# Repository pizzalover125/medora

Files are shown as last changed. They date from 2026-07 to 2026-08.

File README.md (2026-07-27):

# medora
A smart pill organizer. A project that saves lives.

### Why medora?
Medication nonadherence is the failure to take medication as prescribed, whether by skipping doses, taking the wrong amount, or stopping treatment early.

* Medication nonadherence contributes to roughly 125,000 deaths every year in the U.S. (Kim and Sarah A.)
* Pill organizer users saw adherence rise from 65% to as high as 100% within months (Rathod et al.)
* Patients using a smart pill organizer were 60% more compliant than those without one, nearly double the 32% improvement seen with a standard pillbox (Godin)

In the status quo, there smart pill organizers are expensive costing an average of $150 - $200 with an added monthly subscription on top. For many Americans, this is simply too out-of-reach. Additionally, many of the apps that come with the organizers are outdated and hard to use. I wanted to fix this by creating a low-cost, modern, smart pill organizer. 

### PCB

The PCB was designed in KiCAD.





### CAD

The CAD was designed in Onshape. You can view the link here: https://cad.onshape.com/documents/c1d6b76cfe1063ae9996d35d/w/b74057f0558c55e37de9882a/e/dce7fc6940c214e434cc5424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. There are magnets that hold together the lid and the case. 





### BOM 
A detailed bill of materials can be viewed here: https://docs.google.com/spreadsheets/d/15uKd0en9vIonSRlWCDsz52HICyDAk6iSbPfcEML8UvA/edit?usp=sharing.

### Credits
Big thanks to Hack Club for making this project possible!

### Sponsorship

This project's PCBs are sponsored by PCBWay, a leading manufacturer for PCB fabrication, assembly, 3D printing, and more.

#### About PCBWay

PCBWay offers PCB prototyping and manufacturing, PCB assembly, 3D printing, CNC machining, and other on-demand manufacturing services for makers, students, and engineers worldwide.

#### Project Background

This is a smart pill organizer — an 8-compartment device with LED indicators to help users track and remember their medication schedule. Building it required a custom PCB to house the microcontroller, LED drivers, and compartment sensors in a compact enclosure.

#### Order Process

1. **Download the Gerber files** from this repo.
2. **Go to [PCBWay.com](https://www.pcbway.com)** and click **"Instant Quote"** on the homepage.
3. **Upload the Gerber `.zip`** from this repo. PCBWay auto-detects your board dimensions, layer count, and other specs — verify these match: 190mm × 90mm, 2-layer.
4. **Set your order specs:**
   - Quantity (e.g. 5 or 10 boards)
   - Board thickness (1.6mm)
   - Copper weight (1oz standard)
   - Surface finish (HASL or ENIG)
   - Solder mask & silkscreen color
5. **Review the quote** and confirm cost/production time.
6. **Place the order** and confirm shipping address/method.
7. **Track production** — PCBWay provides status updates through fabrication and a tracking number once shipped.

#### Unboxing

Will be updated once I receive the boards!

#### Board Dimensions & Precision

Board size: 190 mm × 90 mm
Board thickness: 1.6 mm (standard)
Copper layers: 2-layer
Minimum trace width: 0.2 mm (KiCad default)
Minimum clearance: 0.2 mm (KiCad default)
Via diameter / drill: 0.6 mm / 0.3 mm (KiCad default)
Surface finish: HASL

#### End Application

The board powers the pill organizer's control system — driving LED indicators for each of the 8 compartments and interfacing with the microcontroller to track dosage timing.

#### Why PCBWay
* Fast turnaround for prototyping
* Reliable build quality at low cost for small-batch orders
* Easy Gerber upload and ordering process
* Good support for hobbyist and student projects

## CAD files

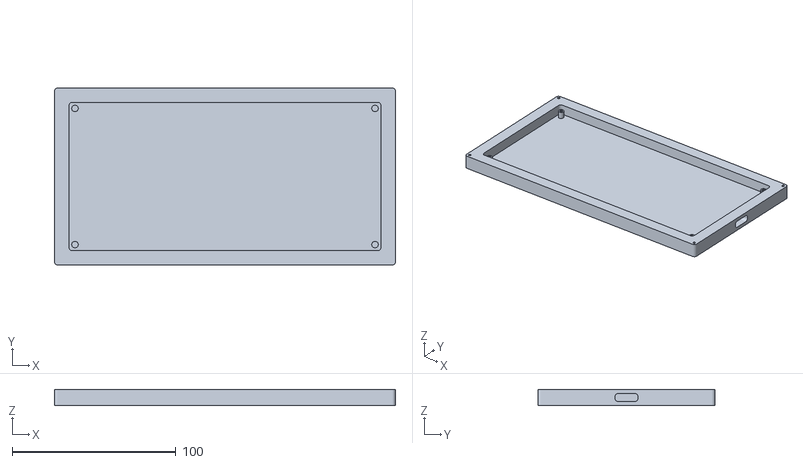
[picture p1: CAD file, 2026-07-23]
CAD/lid bottom.stl
208.0 x 108.0 x 10.0

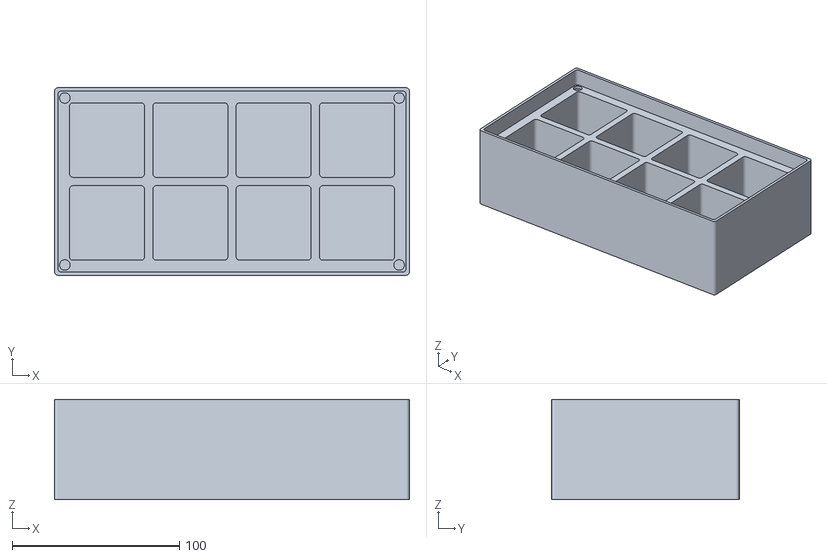
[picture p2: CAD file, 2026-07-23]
CAD/container.stl
212.0 x 112.0 x 60.0

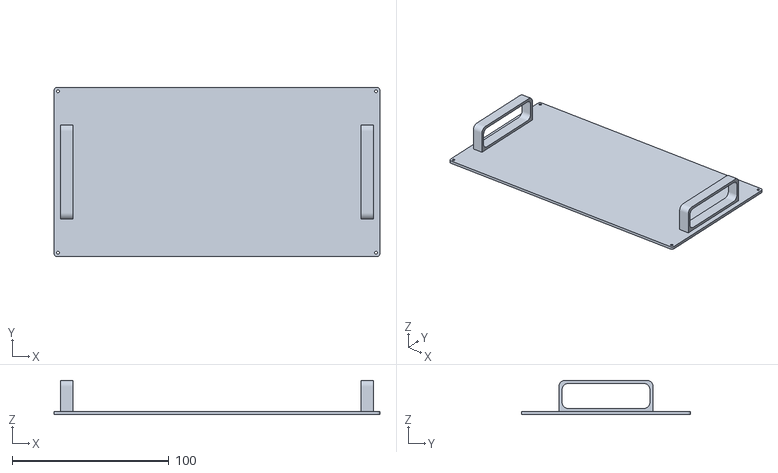
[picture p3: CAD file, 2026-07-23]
CAD/lid top.stl
208.0 x 108.0 x 22.0

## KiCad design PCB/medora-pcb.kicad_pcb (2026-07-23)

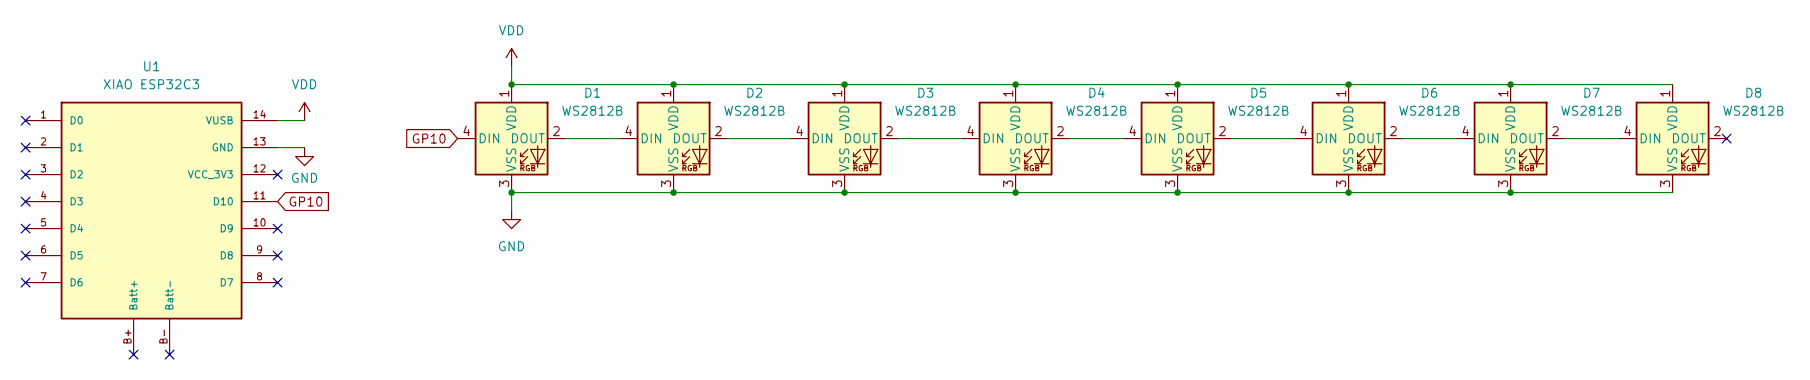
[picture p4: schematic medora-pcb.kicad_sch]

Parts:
D1, D2, D3, D4, D5, D6, D7, D8: WS2812B; LED_WS2812B_PLCC4_5.0x5.0mm_P3.2mm
U1: XIAO ESP32C3; xiao_esp32c3

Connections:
GND: D1.3 (VSS), D2.3 (VSS), D3.3 (VSS), D4.3 (VSS), D5.3 (VSS), D6.3 (VSS), D7.3 (VSS), D8.3 (VSS), U1.13 (GND)
GP10: D1.4 (DIN), U1.11 (D10)
unnamed: D1.2 (DOUT), D2.4 (DIN)
unnamed: D2.2 (DOUT), D3.4 (DIN)
unnamed: D3.2 (DOUT), D4.4 (DIN)
unnamed: D4.2 (DOUT), D5.4 (DIN)
unnamed: D5.2 (DOUT), D6.4 (DIN)
unnamed: D6.2 (DOUT), D7.4 (DIN)
unnamed: D7.2 (DOUT), D8.4 (DIN)
VDD: D1.1 (VDD), D2.1 (VDD), D3.1 (VDD), D4.1 (VDD), D5.1 (VDD), D6.1 (VDD), D7.1 (VDD), D8.1 (VDD), U1.14 (VUSB)

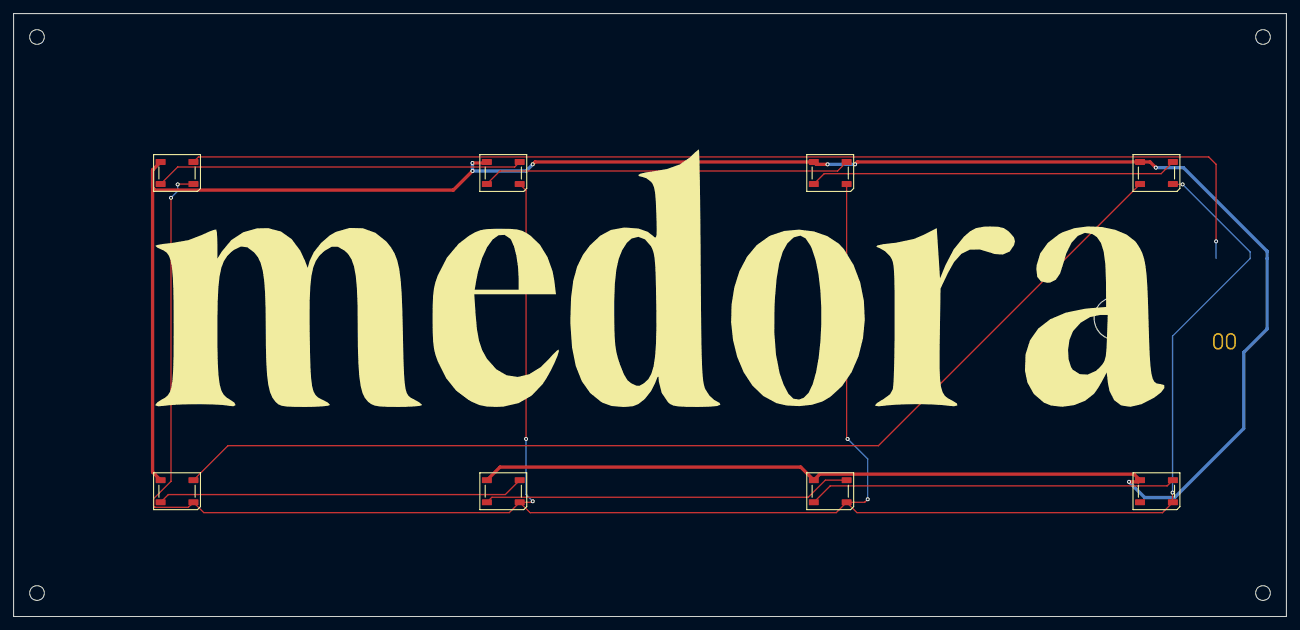
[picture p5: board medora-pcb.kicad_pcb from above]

Board: 2 copper layers, 190.0 x 90.0 mm, 9 parts (1 on the bottom side), 10 nets.

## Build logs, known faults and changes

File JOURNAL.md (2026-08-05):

# journal

### 5/24 (90 min)
- i started this project a while back
- the idea is to create a smart pill organizer
- lots of seniors die due to improper medication
- the status quo is filled with overpriced solutions
- my previous work can be viewed here: https://docs.google.com/document/d/1gj0a-iJIHle2tvecCM2r5ncjlf6axlyIEGGkNLvfImo/edit?tab=t.5onzl3533ios
- i've alr made the schematic... time for PCB!



- ill research some dimensions
- ok did some more research on the problem
- ill start with CAD because I need to visualize the exact design
- The EllieGrid dimensions in millimeters are approximately 197 mm × 108 mm × 32 mm. (thing below)



- used Claude to calculate dimensions




- looks pretty decent!
- ok i made the general design




- renders are sooooo awesome
- going to watch https://www.youtube.com/watch?v=kKsVUTRPM3k to learn more
- built a lid!



- added the cutout



- seems like printing PETG/PLA is not food-safe so i'll need containers
- might redesign the case to add the containers
- but that shouldn't be a problem for v1 of this

### 6/6 (1 hour)
- going to work on PCB now!
- seems like some of the footprints got corrupted
- will fix!



- fixed!
- calculated these values:

Top row (y = 28):
(26.13, 28)
(74.38, 28)
(122.63, 28)
(170.88, 28)

Bottom row (y = 80):
(34.17, 80)
(98.50, 80)
(162.83, 80)

- these took a while lol
- did not think id use mean function this much back when i was in like 4th grade



- looks pretty good



- added 3d model of Xiao!



- routing done!

### 6/7: 1hr
- ok first things first imma add mounting holes



- voila!
- before i modify the CAD, i want to create a quick BOM
- ok its $31.18 for the parts at a quantity of 5
- 5 PCBs comes out to 26.65 at quantity of 5
- ok 11.56 / PCB + CAD costs
- SEEED Studio kinda broken rn but
- so hopefully under ~$20!
- thats great to hear
- time to start up CAD!



- super quick iteration!

### 6/19 (2 hours)
- okay haven't worked on this in a hot minute
- have been working on other projects
- time to lock in for this!
- first thing: delete m2 holes and add m3
- bruh i have to reroute because i have to move microcontroller down



- asked that question in Slack to make sure



- going to do what alex recommended and just work with a rough sketch in CAD of the PCB
- i think ill make it battery powered cause it shouldnt be too hard to?
- i could just easily wire up a lipo to the thing



- redesigned it
- going to look up what mates are
- added screws
- watching https://www.youtube.com/watch?v=0hI57MksVyk



- works pretty well!



- added USB-C hole



- added mounting holes for top
- i have to make this less thick some way
- going to add holes for LEDs



- added the holes!



- added display hole
- realized actual display isn't even centered



- ok im going to add an actuall border cause i'm using exact dimensions



### 6/20: 2 hours
- i had this idea
- what if I made a full ecosystem of products that all communicate with one another using ESPNOW
- Smart pill organizer, sensor that detects if you leave your bed, etc
- will start with this



- made it thinner



- made the border thicker
- it looks like a small change but I had to literally edit every single dimension



- fastened the bolts



- redid the usb-c cutout



- i want to remove that pesky cutout
- this looks like my video: https://www.youtube.com/watch?v=PiJp0BrjR3Q
- im actually learning so many CAD skills



- noice



- looking back, i dont really need the OLED and buttons
- I'm going to be designing an app for this
- ok time to edit the PCB
- also my PCB was large for literally no reason



- okay made it a lot smaller and better
- need silkscreen art tho
- need a logo



- im thinking about adding a battery
- it would be pretty cool, ngl
- ESP32-c3 has built-in
- made it a lot smaller




- looks a lot better ngl

### 6/22: 1 hour
- going to start with CAD now
- wait im going to move the resistors to the other side



- flipped! noice
- will export 3d model



- ok im going to flip the MCU and move the LEDs down



- voila!



- designing with tolerances is soooo hard

### 6/23: 1 hour
- ok ill come back to this
- lets design the case
- idk if I even need a PCB
- it makes it a lot cleaner tho
- im just going to restart it cause i messed something up



- took way longer than it should have



- fixed this resistor i misplaced



- thinned it down



- added holes... time to make the top!

### 6/29: 30 min
- going to make top holes now



- done



- need to make it better
- ok i think ill need to hotplate this because its too thick
- going to use neopixels cause they are better and I could make this sleeker
- im going to use WS2812B

### 7/03: 1.5 hrs
- going to redesign schematic with neopixels



- ok i dont think i need to model it exactly like the other thing
- planning to do 8 containers with a CAD of 200 x 100 mm



- thats what claude came up with



- pretty nice



- added mounting holes; took wayyy longer than expected



- noice



- 3d view looks pretty clean, ngl
- i will create case now
- lets start afresh



- just realized it wouldn't work because the USB-C is too far away



- redesigned it to be 198.5 mm wide so its easy to plug in



- made it 195 x 95 cause it looks too thin in CAD



- still kinda thin, ngl
- going to make it even smaller PCB



- 190 x 100 now!



- hanging over the edge



- it was also mis-centered
- fixed that as well



- nvm not centered



- voila!
- will design lid to lid



- looks like an ominous box
- im going to flip the MCU so it is thinner



- fixed!



- made top part thinner where LEDs will be so it shines brighter



- still looks like a box ngl



- duo-tone design



- container!

### Jul 22 (2 hours)
- ok its time to lock in
- im submitting this to Congressional App Challenge



- added slot
- i want to add magnets
- not enough space



- i added the holes



- added more holes



- looks pretty ugly
- im ready to submit almost
- it looks really ugly
- will fix later
- im going to create a BOM rq





- this doesn't count hotplate
- im going to figure out how much it would cost for 100
- ok it comes out to around $25/unit
- ill figure that out later
- ok im going to set up repo for submission
- prepared the repo!

### Jul 24 (30 min)
- trying to make an exploded view



- looks weird ngl



- modeled the magnet



- looks good!

### Jul 25 (40 min)
- i want to render this cause why not
- imported it into Fusion
- there was some stuff wrong with it but i ended up fixing it
- I asked Claude to help me
- after struggles, i got this!



### Jul 26
- ok i realilze i have a problem



- i have to fix it



- ok that ended up fixing it
- idk how im going to print this
- cause supports wouldn't work... or would they
- i asked in Slack hopefully someone responds

- i downloaded the EllieGrid app to see how it works
- i will use this for my app



- brainstormed what pages will be on the site
- idk if i should journal this here

### 7/27 (2.5 hrs)
- PCBWay reached out to sponsor my hackathon
- my hackathon was too close, so I said we could collaborate in the future
- i also asked if they could sponsor this project
- they said yes!
- i just need to update PCB + repo
- done!
- will email now

- ok i need to fix 3d print also
- right now, it's not printable
- the handles and the rectangle on both sides is too big of an overhang
- so ill split the handles



- added holes



- made the handle
- used calipers IRL to gauge what dimensions i need



- noice!
- will adjust the dimensions
- ok im going to figure out how long ts will take to print

container: 4h45m, 212g
lid top: 49m14s, 33g
lid bottom: 1h33m, 64g
handles: 18m32s, 7g

- thats in total: 7h 25m, 316 g
- i think ill need to add 1kg filament because i'll likely need to reprint stuff

- apparently 1 screw isn't enough
- ok i need to add 2 screws



- nice!
- i added 3 screws cause why not
- i might not use all of them; we'll see



- new cutout
- also larger

### Jul 28 (4 hr)
- i went to the dollar store today
- i got a pill organizer
- im going to make it smart!
- $5 BOM
- THT components so its easy to assemble

- im starting with taking measurements
- it took so long for some reason
- but i got it done
- ive never used calipers before
- i always just use a GrabCAD model
- i got calipers from OpenSauce
- so ill just use those
- i also needed to use rulers because calipers were too small
- test print time!



- it was originally bigger, but Raygen told me to make it 1mm tall
- so i did that!
- first is too tall but not wide enough
- changed dimensions a little bit
- hopefully it works this time
- 2nd one didn't work
- 3rd works but not ideal
- 4th ones the charm
- ok it works
- could be a bit wider but im done with test prints
- ok i need to figure out where to put LEDs
- uhhh ill just work on KiCAD rn
- this is going to require A LOT of prototyping
- i've been trying to find a kicad model for so long
- i do not want to make my own kicad model
- looks like i cant use THT neopixels
- ill just use RGB leds
- ok looks like i can't do THT
- thats unfortunate

### Jul 29
- bruhhh this got deleted
- ok ill rewrite
- basically, i found a THT LED on KiCAD that Claude didn't know about



- i made the schematic
- i tried to find the dimensions on Dollar Tree's website
- i calculated the LED position with Claude
- PCB:



- ok im making it a little bit longer



- noice
- im going to print ts out
- ok i printed two pages out
- the dimensions feel right
- the LEDs feel centered
- i cant be sure tho
- so ig ill just go with it



- i had to update the library
- it works!
- time to start CAD



- ok i was thinking to have two seperate panels
- but im just going to have display under the thing
- ok i dont want to work on CAD ngl
- ill make a render of the PCB



- made it!
- its not the best or anything
- but it looks cool

blue
green
red

- ok lowk this was unneccesary cause ill prob change some stuff
- but its still cool

# august 4th (30 min)
- ok what i did last time was kind of a waste
- didn't really need that
- lets work on the actual CAD



- ok took me a bit to get here
- i made a bunch of mistakes
- idk this feels so odd
- im going to lock in on the other project and come back to ts
